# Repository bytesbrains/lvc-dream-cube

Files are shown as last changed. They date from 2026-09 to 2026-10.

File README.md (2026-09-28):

# LVC Dream Cube

**A colourful puzzle cube you can also solve by touch.**

Each colour on the cube gets its own 3D tactile pattern, so every face can be recognised through touch, not only sight. We 3D-printed small pattern chips and glued them onto an ordinary 3×3 puzzle cube. That's the whole trick, and this repo has everything you need to make one.

🏠 **Little Voice Club:** https://www.littlevoice.club (the home of LVC Dream, which runs and backs this project)  
🌐 **Landing page:** https://bytesbrains.github.io/lvc-dream-cube/  
🚀 **Kickstarter:** [LVC Dream Cube on Kickstarter](https://www.kickstarter.com/projects/bytesbrains/lvc-dream-cube-the-puzzle-cube-you-can-solve-in-the-dark): **live now!** Back it, or share it with someone who would love it.  
📣 **Follow @LittleVoiceClub:** [X](https://x.com/LittleVoiceClub) · [Instagram](https://www.instagram.com/littlevoiceclub/) · [YouTube](https://www.youtube.com/@LittleVoiceClub)

<p align="center">
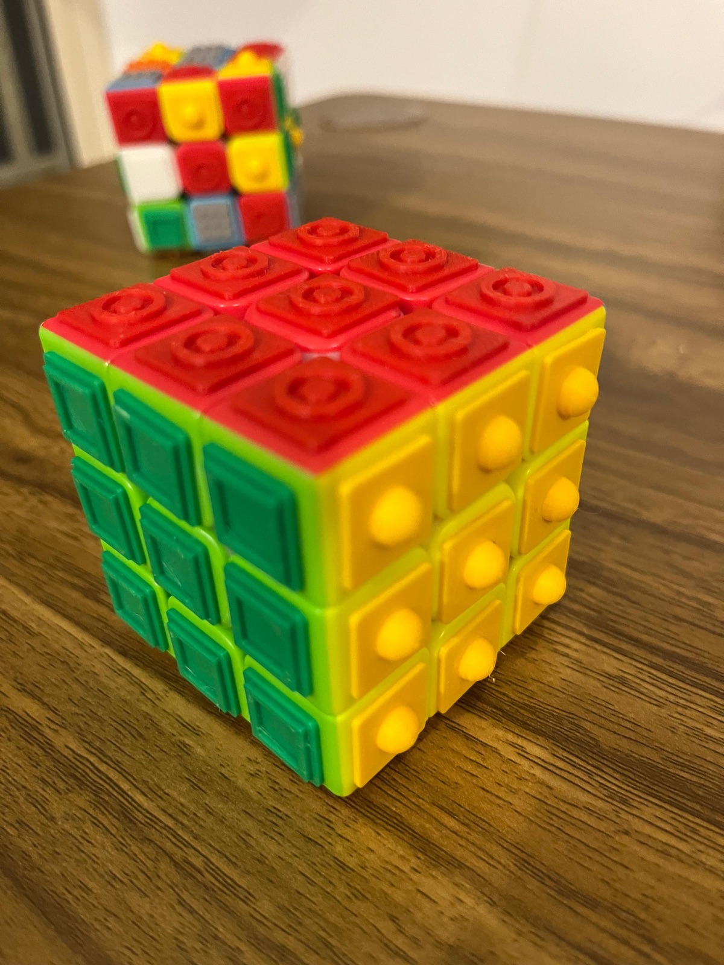
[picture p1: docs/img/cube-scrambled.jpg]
A scrambled LVC Dream Cube. Every coloured square carries a raised chip: grey dots, yellow domes, red rings, green frames, orange ridges and smooth white.
  
</p>

## Who it's for

- **Colour-vision differences:** texture works alongside colour, so a player never has to guess red from green.
- **Blind and visually impaired players:** the whole puzzle can be explored and solved by touch.
- **Everyone else:** close your eyes or play in the dark, and it turns into a new challenge of touch, spatial memory and focus.

The LVC Dream Cube is the first prototype from **LVC Dream**, the accessibility vision inside [Little Voice Club](https://www.littlevoice.club). We don't want to build a separate little world of "accessible products". We want the things everyone already loves (toys, games, learning tools, art materials) to work for more people through thoughtful design.

## The tactile key

| Colour | Texture | Feels like | Model file |
|---|---|---|---|
| ⬜ White | **Smooth** | Flat chip, no relief | [`rubik_36x_smooth_white.3mf`](models/rubik_36x_smooth_white.3mf) |
| 🟩 Green | **Frame** | Raised square border | [`rubik_36x_frame_green.3mf`](models/rubik_36x_frame_green.3mf) |
| 🟧 Orange | **Ridges** | Diagonal ridges | [`rubik_36x_ridges_orange.3mf`](models/rubik_36x_ridges_orange.3mf) |
| 🟥 Red | **Rings** | Concentric circles | [`rubik_36x_rings_red.3mf`](models/rubik_36x_rings_red.3mf) |
| 🟦 Blue | **Dots** | A grid of small bumps | [`rubik_36x_dots_blue.3mf`](models/rubik_36x_dots_blue.3mf) |
| 🟨 Yellow | **Dome** | One large rounded bump | [`rubik_36x_dome_yellow.3mf`](models/rubik_36x_dome_yellow.3mf) |

The textures are chosen to feel clearly different from one another, going from flat (white) up to the tallest relief (yellow dome).

## What's in this repo

```
models/
  rubik_all54_tiles.3mf        # one full cube: 9 chips of each texture, one plate
  rubik_36x_<texture>_<colour>.3mf   # 36 chips of one texture (enough for 4 cubes)
docs/                          # the GitHub Pages landing page
PRINTING.md                    # print settings and assembly guide
```

Every chip is a **12 × 12 mm** square on a 1 mm base. The per-colour plates lay chips out in a 6 × 6 grid at a 15.5 mm pitch. The files are 3MF meshes exported from OpenSCAD and open in any modern slicer (PrusaSlicer, Bambu Studio, OrcaSlicer, Cura).

## Make your own

1. Get an ordinary 3×3 puzzle cube. Measure one sticker; the chips are 12 mm, which fits a standard 57 mm cube.
2. Print either `rubik_all54_tiles.3mf` (single-colour print, one cube) or the six per-colour plates in matching filament.
3. Glue each chip onto the matching colour, then check every face by touch before you play.

Full instructions, including the settings we recommend, are in [PRINTING.md](PRINTING.md).

## Build with us

We'd love to work with toy makers, accessibility researchers, educators, designers, manufacturers and brands on testing this idea with the communities it's meant for, and on making accessible products at scale.

- Printed one? [Share a photo or feedback](https://github.com/bytesbrains/lvc-dream-cube/issues/new?template=i-made-one.md).
- Have a better texture, a new chip size or a braille variant? See [CONTRIBUTING.md](CONTRIBUTING.md).
- Want to partner or manufacture? Email **hello@littlevoice.club**.

## License

The design files, photos and documentation are released under [Creative Commons Attribution 4.0 (CC BY 4.0)](LICENSE). You may print, remix, sell and manufacture them. Just credit **LVC Dream / Little Voice Club** and link back to this repository.

"Little Voice Club", "LVC Dream" and the Little Voice Club logo are trademarks and are not covered by the licence.

*LVC Dream: imagine, build and play for everyone.* 🌈

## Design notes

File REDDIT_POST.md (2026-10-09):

# Reddit Community Outreach — Copy & Paste Kit

Ready-to-use posts tailored for **r/Cubers**, **r/blind**, and **Hacker News (Show HN)** to share the **LVC Dream Cube** and drive organic backers to the Kickstarter campaign.

---

## 1. r/Cubers Post (Primary)

* **Target Subreddit:** [r/Cubers](https://www.reddit.com/r/Cubers/)
* **Recommended Flair:** `MOD` or `HARDWARE`
* **Image to Attach:** Upload `docs/img/cube-scrambled.jpg` or `docs/img/banner.png` directly to the Reddit post!

### Title (Copy this)
```text
I designed an open-source tactile 3x3 so anyone can solve purely by touch (in the dark or for visually impaired cubers) — 3D print files free on GitHub!
```

### Post Body (Copy the block below)

```markdown
Hey r/Cubers,

For the past few months, we’ve been working on an open project to make the 3×3 puzzle universal: the **LVC Dream Cube**.

Instead of relying solely on stickers or colours, every face carries its own unique 3D tactile texture so you can identify pieces and solve the entire cube purely by touch and spatial memory.

### The Tactile Texture Key:
* ⬜ **White:** Smooth (flat chip, zero relief)
* 🟩 **Green:** Frame (raised square border)
* 🟧 **Orange:** Diagonal Ridges
* 🟥 **Red:** Concentric Rings
* 🟦 **Blue:** Grid of Dots
* 🟨 **Yellow:** Dome (single large rounded center bump)

The textures are arranged by physical relief height—going from flat (white) up to the tallest relief (yellow dome)—making tactile recognition intuitive with minimal fingertip practice.

### Why we built it:
1. **Blind & Visually Impaired Players:** A blind person can solve the cube independently without fragile braille stickers. Sighted and visually impaired cubers can compete on the exact same hardware side-by-side.
2. **Colour-Vision Differences:** Texture works alongside colour, so players never have to second-guess red, green, or orange.
3. **The "Dark Solve" Challenge:** For anyone who loves BLD or wants a new sensory brainteaser—close your eyes or play in the dark. It tests tactile memory in a completely fresh way.

### 100% Free & Open-Source (CC BY 4.0):
We didn't want this locked behind a paywall. Every 12×12 mm chip file (designed to fit standard 56mm / 57mm cubes without hindering outer edge finger-tricks) is open-sourced under Creative Commons Attribution on GitHub:
👉 **GitHub Repo (3MF/STL print files):** https://github.com/bytesbrains/lvc-dream-cube  
👉 **Project Landing Page:** https://bytesbrains.github.io/lvc-dream-cube/

You can slice and 3D print the chips yourself today, glue them onto an inexpensive budget cube (like an RS3M or Drift 3x3), and play right away.

### Scaling to Injection Moulding (Kickstarter):
3D printing is great for makers, but blind schools, special educators, and kids need factory-fitted, durable injection-moulded tiles. We launched our Kickstarter campaign from Singapore to fund our first factory production batch and distribute classroom packs to blind schools:
👉 **Kickstarter Campaign:** https://www.kickstarter.com/projects/bytesbrains/lvc-dream-cube-the-puzzle-cube-you-can-solve-in-the-dark

I would love to get the community's thoughts:
* What do you think of the texture progression?
* Would you try a tactile-only solve in the dark?
* Any ideas for custom finger-feel or core tensioning adjustments for tactile solves?

Happy to answer any questions or hardware feedback in the comments!
```

---

## 2. r/blind Post (Secondary)

* **Target Subreddit:** [r/blind](https://www.reddit.com/r/blind/)
* **Recommended Flair:** `Resource / Technology`

### Title
```text
Open-source tactile puzzle cube (solve by touch without braille) — free 3D print files + Kickstarter for school packs
```

### Post Body

```markdown
Hi r/blind,

I wanted to share a project we've been working on at Little Voice Club (based in Singapore): the **LVC Dream Cube**.

The goal was to make the iconic 3×3 puzzle completely solvable by touch, without requiring braille literacy, and without separating visually impaired players into a "special" silo.

### How it works:
Every colour is mapped to an embossed geometric texture on a 12×12 mm chip:
* White = Smooth (completely flat)
* Green = Frame (raised square border)
* Orange = Diagonal Ridges
* Red = Concentric Rings
* Blue = Grid of Dots
* Yellow = Dome (large rounded bump)

By running your fingers across the pieces, you can identify corners, edges, and centers by touch alone. Sighted friends and visually impaired players can solve the exact same puzzle together.

### Free Open Hardware:
All 3D CAD files are free under Creative Commons (CC BY 4.0) on GitHub so anyone with a 3D printer can make one locally:
👉 https://github.com/bytesbrains/lvc-dream-cube
👉 Project info: https://bytesbrains.github.io/lvc-dream-cube/

### Getting them to blind schools & non-makers:
For students and families who don't have access to 3D printers, we launched a Kickstarter to fund factory injection-moulded production and deliver classroom packs to special education schools:
👉 https://www.kickstarter.com/projects/bytesbrains/lvc-dream-cube-the-puzzle-cube-you-can-solve-in-the-dark

Would love to hear your feedback on the textures and how we can make tactile puzzle play even more accessible!
```

---

## 3. Hacker News (Show HN)

* **Platform:** [news.ycombinator.com](https://news.ycombinator.com/submit)

### Title
```text
Show HN: LVC Dream Cube – Open-source tactile 3x3 puzzle cube you can solve by touch
```

### URL
```text
https://bytesbrains.github.io/lvc-dream-cube/
```

### Text (First Comment from submitter)
```text
Hi HN,

We built the LVC Dream Cube: an open-source hardware mod that makes the classic 3×3 puzzle solvable entirely through touch and spatial memory.

Each face is mapped to an embossed geometric texture (Smooth, Frame, Ridges, Rings, Dots, Dome) on 12×12 mm tiles that fit standard 56mm cubes.

It solves three problems:
1. Complete tactile independence for blind and low-vision players without requiring braille notation.
2. Removes colour-blindness ambiguity (red/green/orange).
3. A sensory "dark solve" challenge for sighted cubers.

All print files are CC BY 4.0 on GitHub: https://github.com/bytesbrains/lvc-dream-cube

We also launched a Kickstarter from Singapore to fund an initial injection-moulded production run for blind schools: https://www.kickstarter.com/projects/bytesbrains/lvc-dream-cube-the-puzzle-cube-you-can-solve-in-the-dark

Feedback on the mechanical tolerances and tactile textures is very welcome.
```

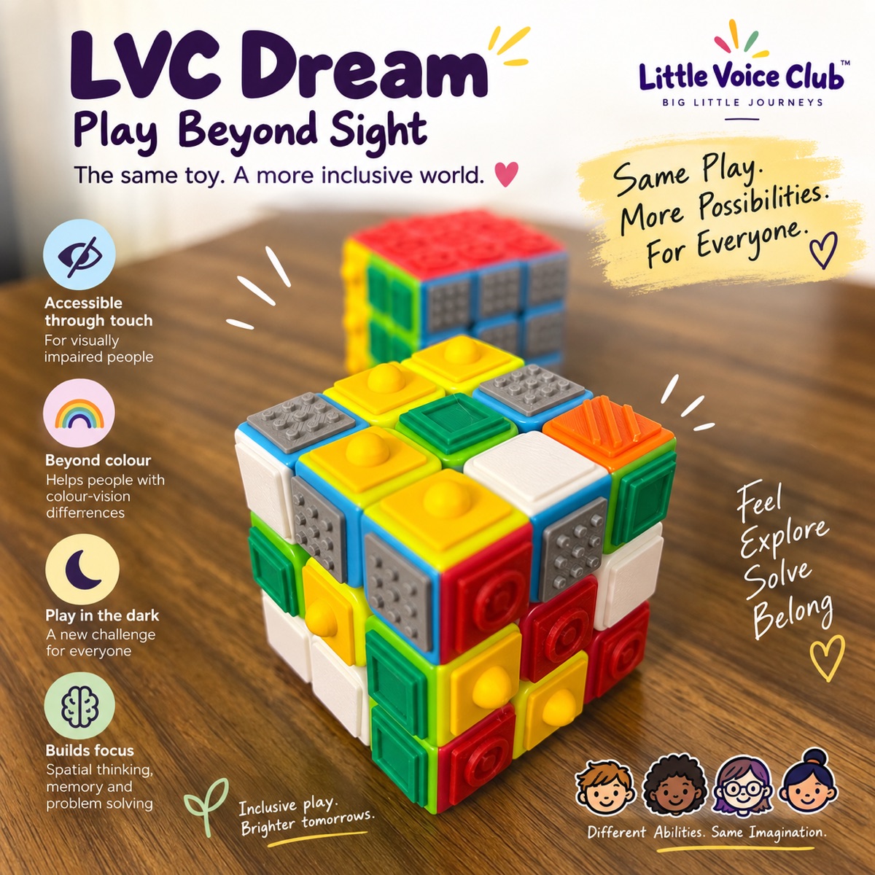
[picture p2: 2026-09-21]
docs/img/lvc-dream-poster.jpg

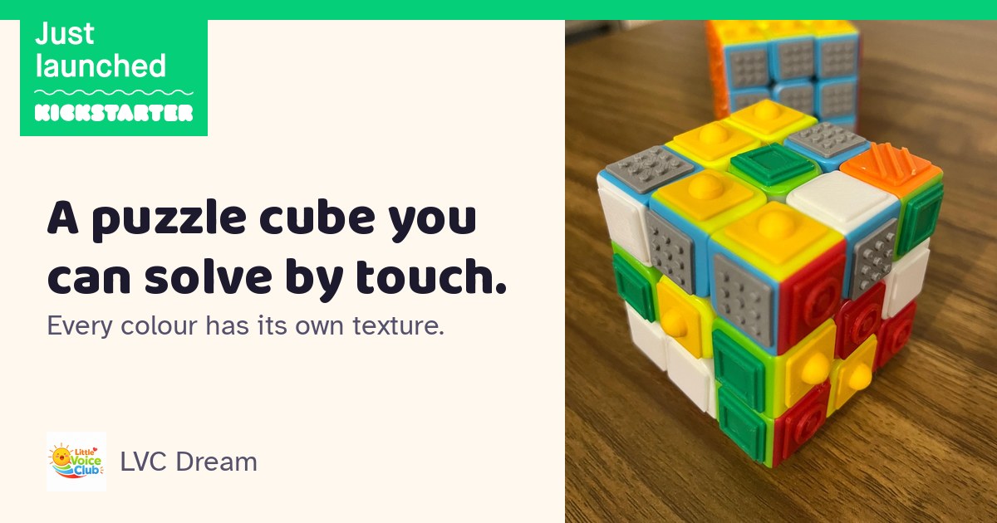
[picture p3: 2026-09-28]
docs/img/og-kickstarter.jpg

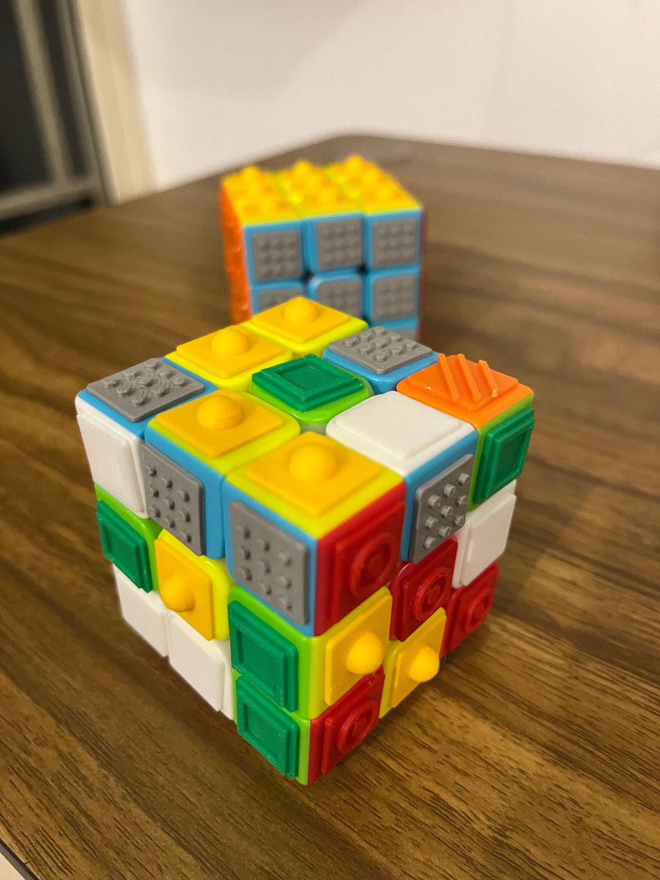
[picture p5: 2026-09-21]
video/img/cube-scrambled.jpg

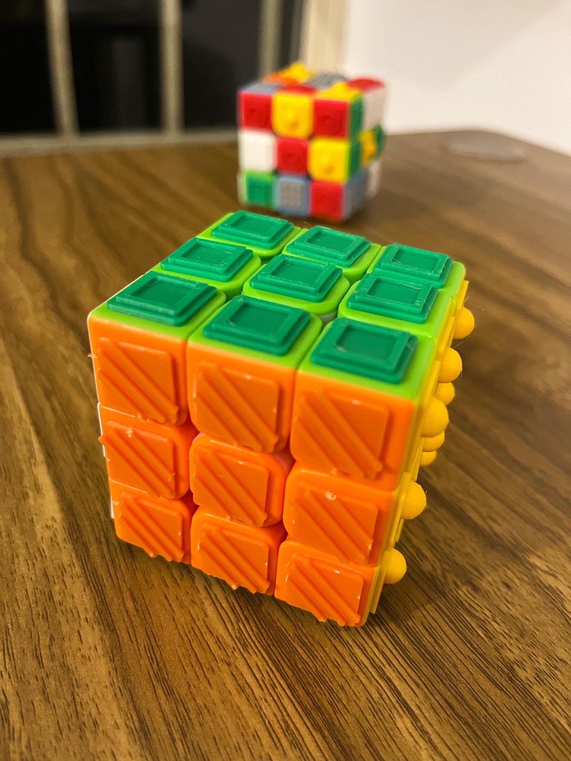
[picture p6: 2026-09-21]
video/img/cube-green-orange.jpg

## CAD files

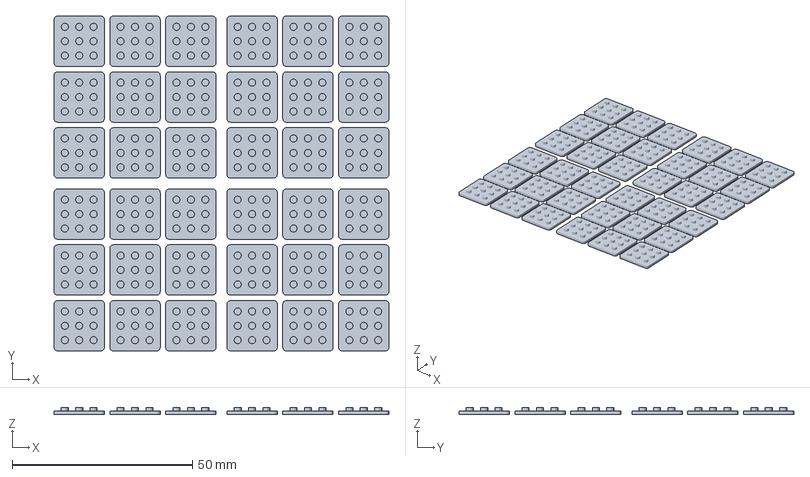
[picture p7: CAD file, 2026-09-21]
models/rubik_36x_dots_blue.3mf
93.0 x 93.0 x 2.00 mm

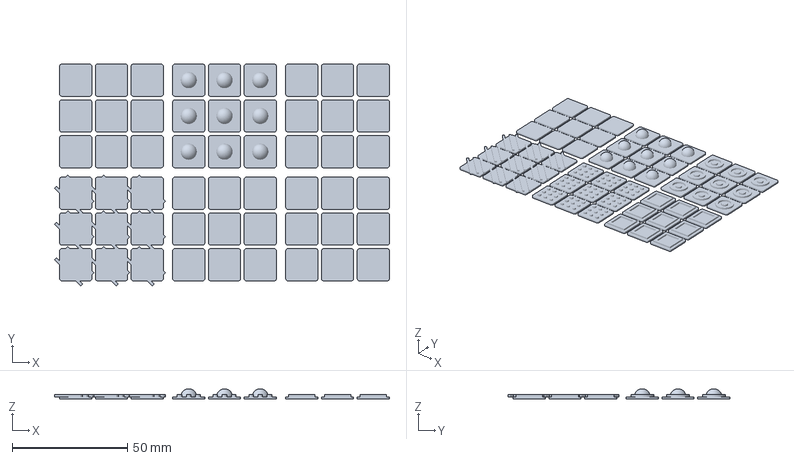
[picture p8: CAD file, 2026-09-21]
models/rubik_all54_tiles.3mf
145.2 x 96.2 x 4.49 mm

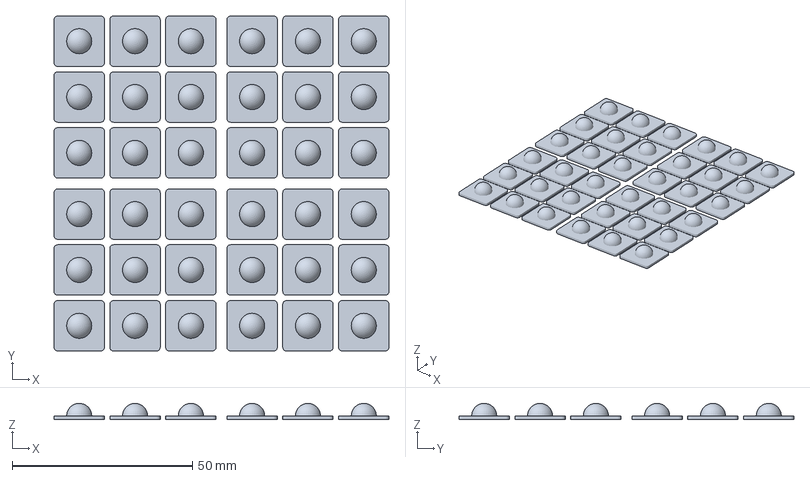
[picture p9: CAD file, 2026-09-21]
models/rubik_36x_dome_yellow.3mf
93.0 x 93.0 x 4.49 mm

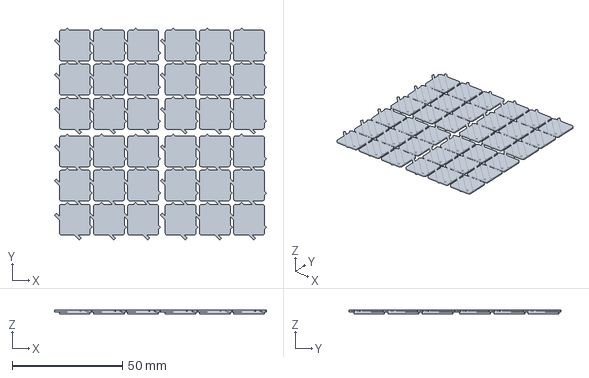
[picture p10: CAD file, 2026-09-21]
models/rubik_36x_ridges_orange.3mf
96.1 x 96.1 x 2.00 mm

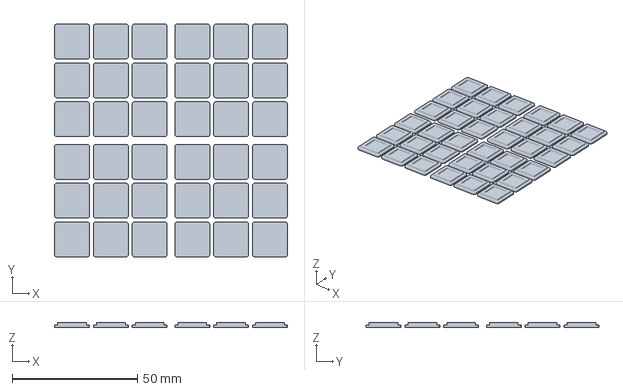
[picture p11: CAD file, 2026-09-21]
models/rubik_36x_frame_green.3mf
93.0 x 93.0 x 2.00 mm

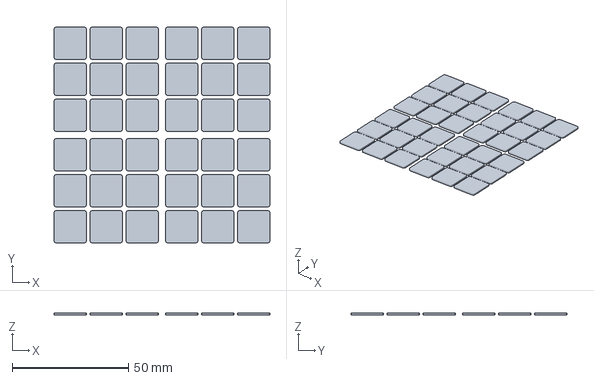
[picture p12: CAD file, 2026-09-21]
models/rubik_36x_smooth_white.3mf
93.0 x 93.0 x 1.00 mm

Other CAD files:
models/rubik_36x_rings_red.3mf

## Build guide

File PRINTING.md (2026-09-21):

# Printing & assembly guide

## 1. Check your cube

The chips are **12 × 12 mm**. That fits a standard 57 mm 3×3 cube, whose stickers or tiles are about 15–16 mm across. If your cube is smaller or bigger, scale the model in your slicer. Scale X and Y only and keep Z (height) at 100%, so the textures stay just as easy to feel.

## 2. Choose your files

| Option | File(s) | When to use |
|---|---|---|
| One cube, one filament | `models/rubik_all54_tiles.3mf` | Fastest route. Chips come out one colour, so paint them or rely on the cube's own colours showing around them. |
| Colour-matched chips | The six `models/rubik_36x_*.3mf` plates | Print each plate in its matching filament. Each plate holds 36 chips, enough for 4 cubes. |

Tactile key: white = smooth · green = frame · orange = ridges · red = rings · blue = dots · yellow = dome.

## 3. Suggested slicer settings

These are starting points, not hard rules. Any FDM printer should work.

- **Material:** PLA or PETG
- **Nozzle:** 0.4 mm
- **Layer height:** 0.12–0.16 mm for dots, rings and dome (crisper detail); 0.2 mm is fine for smooth, frame and ridges
- **Infill:** 100% (the chips are tiny)
- **Supports:** none; every chip prints flat side down
- **First layer:** a clean, flat bed; a textured PEI plate gives the chip backs grip for glue

## 4. Assemble

1. Clean the cube faces with a little isopropyl alcohol.
2. Glue one face at a time, matching each chip to its colour. A thin cyanoacrylate gel or strong double-sided tape both work; use as little as possible so nothing squeezes into the cube's gaps.
3. Keep chips centred on each tile, so they don't catch when the layers turn.
4. Let it cure, then close your eyes and check every face by touch before you scramble it.

## 5. Safety

Chips are small parts. Adults should assemble the cube, and it isn't suitable for children under 3. Check regularly that no chip has come loose.

Printed one? Please [share a photo or feedback](https://github.com/bytesbrains/lvc-dream-cube/issues/new?template=i-made-one.md). It helps us improve the design.

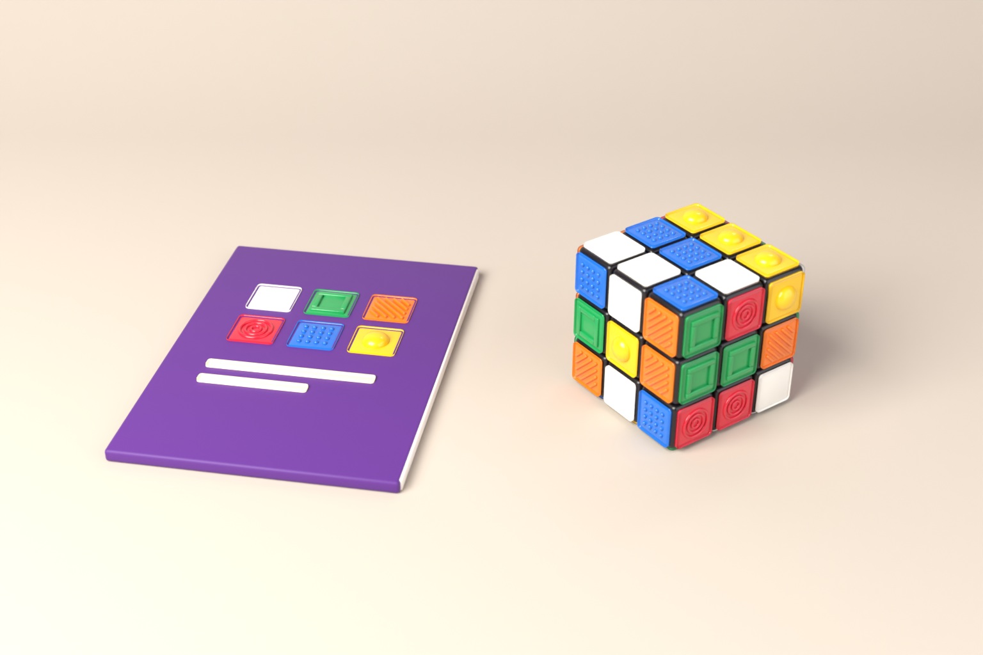
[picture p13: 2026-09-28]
kickstarter/reward-images/item-teaching-guide.jpg

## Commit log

2026-09-21 feat: open-source LVC Dream Cube print files and landing page
    Tactile chip models (3MF) for all six faces, printing and assembly guide,
    contribution templates, CC BY 4.0 licence, and a GitHub Pages landing page
    under docs/ ahead of the Kickstarter campaign.
    [rubik_36x_dome_yellow.3mf, rubik_36x_dots_blue.3mf, rubik_36x_frame_green.3mf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]
2026-09-28 feat: point README and landing page at the live Kickstarter campaign
    Swap the draft project link for the public campaign URL, change the
    "launching soon" labels to "live now", and embed the Kickstarter
    video and project card on the landing page.
2026-09-28 feat: add Kickstarter brand assets and launch banner to the landing page
    - Kickstarter's creator-kit logos and campaign-stage banners in
    docs/img/kickstarter (logos, Just Launched / Nearly Funded / Ending
    Soon / Just Funded)
    - Hero photo carries the "Just launched" banner, linked to the campaign
    - Kickstarter wordmark with a "Live now" pill heads the Kickstarter
    section; green K mark next to the Kickstarter menu link; footer link
    - New 1200x630 link preview (og-kickstarter.jpg) with the launch banner
    - kickstarter/social: script and Instagram / X post images built from
    the real prototype photo with the launch banner
    - Swap cube-scrambled.jpg and cube-red-yellow-green.jpg (docs and vi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
2026-09-28 feat: link Little Voice Club on X, Instagram and YouTube
    Add @LittleVoiceClub links to the landing page footer and README, and
    set twitter:site so X link previews credit the account. Break the
    README link lines so they render on separate lines.
